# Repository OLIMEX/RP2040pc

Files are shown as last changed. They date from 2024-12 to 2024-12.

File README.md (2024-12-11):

# RP2040pc
All in one computer with 4 USB hosts, Stereo Audio, HDMI output. Supports USB Flash drives, USB keyboards, USB Gamepads.

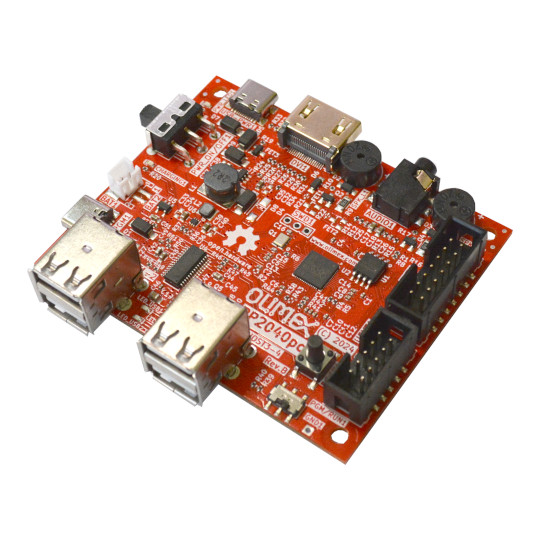
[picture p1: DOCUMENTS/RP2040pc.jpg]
RP2040pc


https://www.olimex.com/Products/RaspberryPi/RP2040pc/

## Licensee
* Hardware is released under CERN Open Hardware Licence Version 2 - Strongly Reciprocal
* Software is released under MIT Licensee
* Documentation is released under CC BY-SA 4.0

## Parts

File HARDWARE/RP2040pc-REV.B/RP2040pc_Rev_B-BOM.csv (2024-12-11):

Id | Designator | Footprint | Quantity | Designation | Supplier and ref
1 | MH1,MH3,MH4,MH2 | Mounting_Hole_Drill-3.3mm_Clerance-7mm | 4 | Mounting_Hole_NPTH
2 | R38,R44,R10,R20,R17,R49,R48,R18 | R_0402_5MIL_DWS | 8 | 2.2k/R0402
3 | R12,R13 | R_0402_5MIL_DWS | 2 | 150R/R0402
4 | R14,R31,R28,R25,R24,R27,R26,R29,R30,R15 | R_0402_5MIL_DWS | 10 | 270R/R0402
5 | FID5,FID6,FID4 | Fiducial1x3 | 3 | Fiducial
6 | FID2,FID3,FID1 | Fiducial1x3_Paste | 3 | Fiducial
7 | C17,C34,C37,C18,C39,C35 | C_0603_5MIL_DWS | 6 | 22uF/6.3V/20%/X5R/C0603
8 | C25,C1,C2,C3,C4,C5,C6,C7,C8,C9,C10,C14,C13,C44,C46,C26,C41,C49 | C_0402_5MIL_DWS | 18 | 100nF/10V/20%/X5R/C0402
9 | AUDIO1 | SCJ325P00XG0B02G | 1 | PJ-3.5-365-5P
10 | Q2,Q4 | SOT23 | 2 | BC817-40(SOT23)
11 | C11,C12 | C_0402_5MIL_DWS | 2 | 2.2uF/6.3V/20%/X5R/C0402
12 | C15,C16 | C_0402_5MIL_DWS | 2 | 18pF/50V/5%/C0G/C0402
13 | Q1,Q5 | TSX-3.2x2.5mm_GND(3) | 2 | Q12MHz/20pF/10ppm/4P/3.2x2.5mm
14 | R1,R45,R23,R46,R19 | R_0402_5MIL_DWS | 5 | 10k/R0402
15 | R2,R43 | R_0402_5MIL_DWS | 2 | NA(10k/R0402)
16 | R6,R8 | R_0402_5MIL_DWS | 2 | 100R/R0402
17 | R4,R5 | R_0402_5MIL_DWS | 2 | 27R/R0402
18 | U1 | SO-8_208mil | 1 | W25Q128JVSIQ
19 | U2 | QFN56_7x7_Pitch_0.4mm | 1 | RP2040(QFN-56_7x7mm_P0.4mm)
20 | BOOT1 | T1102D_6x6 | 1 | T1102D(6x6x9.5mm)
21 | SWD1 | HN1x3 | 1 | NA(HN1x3)
22 | R9,R16 | R_1206_5MIL_DWS | 2 | 47R/R1206
23 | DVI1 | HDMI-SWM-19_Paste | 1 | HDMI-SWM-19
24 | SPK_L1,SPK_R1 | Speaker_QMB-09B-03_1-Plus_2-Minus | 2 | Speaker_QMB-09B-03(1.5-5.0V_2.7kHz_F9.0mm*H5.5mm)
25 | D2,D3 | SOD-123_1C-2A_KA | 2 | 1N4148W/SOD123
26 | C40,C38,C32,C33 | C_0603_5MIL_DWS | 4 | NA(22uF/6.3V/20%/X5R/C0603)
27 | R35 | R_0402_5MIL_DWS | 1 | 1.05k/1%/R0402
28 | USB_HOST1-2,USB_HOST3-4 | USB_TWO_LEVEL | 2 | USBB1-FRWH-4A(USB-Ax2)
29 | LED_USB4,LED_USB3,LED_USB1,LED_USB2 | LED_0603_KA | 4 | LED/GREEN/0603
30 | U6 | SOT-563-6 | 1 | TPS62A02ADRLR(SOT-563-6)
31 | R40,R42,R41 | R_0402_5MIL_DWS | 3 | 470k/R0402
32 | C27,C28 | C_0805_5MIL_DWS | 2 | NA(47uF/6.3V/20%/X5R/C0805)
33 | C29,C19,C30 | C_0805_5MIL_DWS | 3 | 47uF/6.3V/20%/X5R/C0805
34 | R22,R21 | R_0402_5MIL_DWS | 2 | NA(2.2k/R0402)
35 | PWR_ON/OFF1 | SS-12D11G5 | 1 | SS-12D11G5
36 | EXT1 | GBH-254-SMT-14 | 1 | B-V-14-LF
37 | R33,R32,R7,R3 | R_0402_5MIL_DWS | 4 | 5.1k/1%/R0402
38 | U5 | SOT-23-5 | 1 | BL4054B-42TPRN(SOT23-5)
39 | CHARGING1 | LED_0603_KA | 1 | LED/YELLOW/0603
40 | D7,D8,D5,D1,D9 | SMA-KA | 5 | 1N5822/SS34/SMA
41 | UEXT1 | GBH-254-SMT-10 | 1 | P-B-V-10-LF
42 | GND1 | TEST_PAD40x70_SQUARE | 1 | TESTPAD
43 | C31 | C_0603_5MIL_DWS | 1 | 1uF/10V/10%/X5R/C0603
44 | R50 | R_0402_5MIL_DWS | 1 | 47k/R0402
45 | FET2,FET1 | SOT23 | 2 | NA(BSS138(SOT23-3))
46 | U4 | SSOP28_10x4mm_Pitch_0.64mm | 1 | FE1.1s_USB2.0-HUB
47 | PGM/RUN1 | SWITCH_SLIDE_IS-1390-G_TR | 1 | SWITCH SLIDE IS-1390-G TR
48 | U7 | SOT23-6 | 1 | MT3608(SOT23-6)
49 | C43,C45,C42 | C_0603_5MIL_DWS | 3 | 10uF/6.3V/20%/X5R/C0603
50 | U3 | SOT23-6 | 1 | CH217K(SOT23-6L)
51 | R51 | R_0402_5MIL_DWS | 1 | 100k/R0402
52 | USB-PGM1,USB-PWR1 | USB2.0_TYPE-C(A40-00119-A52-12)_Paste | 2 | USB-C-16P-F(A40-00119-A52-12)
53 | FET3 | SOT23 | 1 | WPM2015-3/TR
54 | R47 | R_0402_5MIL_DWS | 1 | 2.7k/1%/R0402
55 | C47,C48 | C_0402_5MIL_DWS | 2 | NA(27pF/50V/5%/C0G/C0402)
56 | BAT1 | LIPO_BAT_VERTICAL_DW02S | 1 | DW02S
57 | R37 | R_0402_5MIL_DWS | 1 | 49.9k/1%/R0402
58 | R36,R39 | R_0402_5MIL_DWS | 2 | 220k/R0402
59 | D6 | SOD-123_1C-2A_KA | 1 | 1N5819S4/SOD123
60 | C36 | C_0402_5MIL_DWS | 1 | NA(120pF/50V/5%/C0G/C0402)
61 | R11 | R_0402_5MIL_DWS | 1 | 33k/R0402
62 | D4 | SMA-KA | 1 | NA(1N5822/SS34/SMA)
63 | R34 | R_0402_5MIL_DWS | 1 | 8.25k/1%/R0402
64 | L1 | YS75_7X8MM | 1 | 2.2uH/3A/YS75/7x8
65 | PWR_LED1 | LED_0603_KA | 1 | LED/RED/0603
66 | BAT2 | PH2.0-2PWB | 1 | NA(PH2.0-2PWB)
67 | L2 | CD32 | 1 | 1.0uH/2.5A/DCR=30mR/20%/3.00x3.00x1.50mm/CD32(SWPA3015S1R0MT)
68 | HCEC1,HSDA1,HSCL1,HHPD1,+5V_USB1,GND2,VBUS1,+5V1,+1V1,VBAT1,VBUS_PWR1,+3.3V1 | TESTPAD_40-ROUND | 12 | TESTPAD

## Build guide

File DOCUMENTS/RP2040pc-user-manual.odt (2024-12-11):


RP2040pc

User Manual

Rev.1.0 December 2024 olimex.com

# What is RP2040pc

RP2040pc is complete all in one computer based on RP2040 Dual core Cortex-M0 processor from the Raspberry Pi foundation.

The features of RP2040pc are:

- RP2040 with 16MB of SPI Flash, easy to load new firmware via drag and drop virtual drive
- DVI/HDMI output
- USB with 4 USB2.0 hub which can be used for programming and to connect to keyboard, mouse, USB Flash, USB Gamepads etc
- Stereo Audio buzzer which you can enable/disable
- Audio 3.5mm connector for external audio amplifier
- USB-C connector for power supply
- USB-C connector for programming
- UEXT connector with I2C, UART and SPI for connecting to external boards
- Power switch
- Programming/Execution switch
- RP2040 programming bootloader button
- four mounting holes 3.3mm diameter
- Lipo battery charger which allow the board to run from LiPo battery.
- Dimension 80x65mm
  RP2040pc is Open Source Hardware, all CAD files and firmware and available, so people can study and modify.

+ Important notice: If RP2040pc is not mounted in box be careful to not place it on metal surface, nor drop metal objects on top of the PCB! This will lead to damage.

## Order codes for RP2040pc and accessories:

RP2040pc (https://www.olimex.com/Products/RaspberryPi/RP2040pc/) RP2040 all in one computer with 4 USB hosts and HDMI display

USB-KEYBOARD-PS2 (https://www.olimex.com/Products/USB-Modules/USB-KEYBOARD-PS2/) Keyboard which is compatible with RP2040pc

USB-GAMEPAD (https://www.olimex.com/Products/Retro-Computers/USB-GAMEPAD/) USB Gamepad supported by Reload emulator

USB-CABLE-AM-USB3-C (https://www.olimex.com/Products/Components/Cables/USB-CABLE-AM-USB3-C/) High speed, High current cable for power supply and programming

CABLE-HDMI-50CM (https://www.olimex.com/Products/Components/Cables/CABLE-HDMI-50CM/) HDMI cable

UEXT modules (https://www.olimex.com/Products/Modules/) many UEXT modules which can connect to Neo6502 UEXT connector

BOX- (https://www.olimex.com/Products/RaspberryPi/BOX-RP2040PC/)RP2040pc (https://www.olimex.com/Products/RaspberryPi/BOX-RP2040PC/) plastic box for RP2040pc

(https://www.olimex.com/Products/Components/Cables/USB-CABLE-AM-USB3-C/)

# HARDWARE

## RP2040pc layout:

USB-C

power supply

DVI/HDMI output

Stereo Audio 3.5mm jack

Left audio

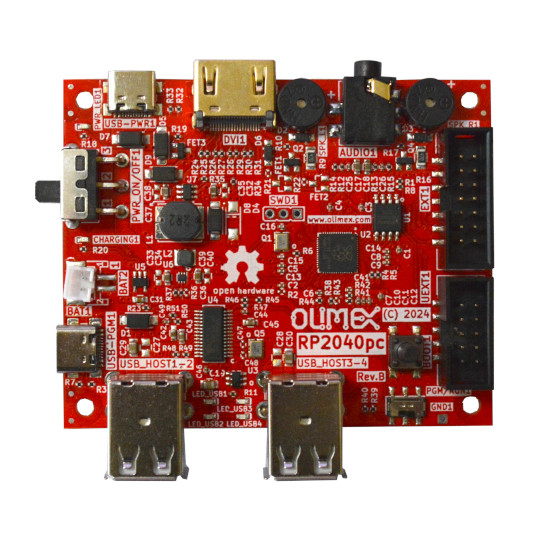
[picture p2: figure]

Right audio

ON/OFF switch

EXT1 connector

LiPo battery

UEXT connector

BOOT button

USB-C programming

Programing / RUN switch

USB2.0 host 1 and 2

USB2.0 host 3 and 4

## RP2040pc EXT1 connector:

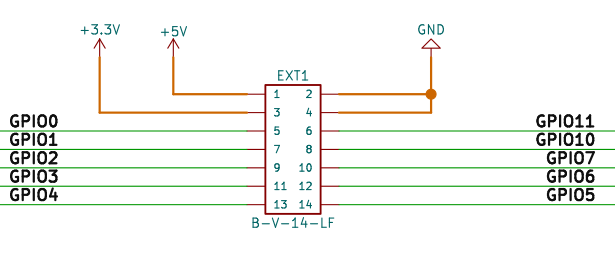
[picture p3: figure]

## UEXT connector:

UEXT connector stands for Universal EXTension connector and contain +3.3V, GND, I2C, SPI, UART signals.

UEXT connector can be in different shapes.

The original UEXT connector is 0.1” 2.54mm step boxed plastic connector. All signals are with 3.3V levels.

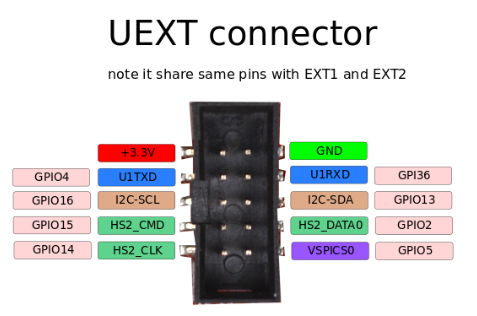
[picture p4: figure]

Olimex has developed number of MODULES (https://www.olimex.com/Products/Modules/) with this connector. There are temperature, humidity, pressure, magnetic field, light sensors. Modules with LCDs, LED matrix, Relays, Bluetooth, Zigbee, WiFi, GSM, GPS, RFID, RTC, EKG, sensors and etc.

RP2040pc UEXT connector is wired to RP2040 GPIOs as follows:

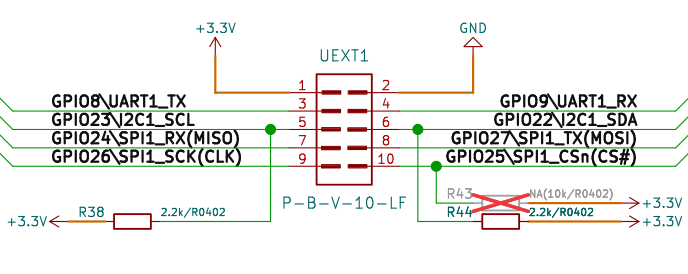
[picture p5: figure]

## RP2040pc schematics:

RP2040pc latest schematic is on GitHub (https://github.com/OLIMEX/Neo6502/blob/main/HARDWARE/Neo6502-rev-B/Neo6502_Rev_B.pdf)

# SOFTWARE:

RP2040pc can be programmed with RaspberryPi C-SDK or MicroPython SDK.

(https://github.com/vsladkov/reload-emulator)

For the retro computing fans the Reload (https://github.com/vsladkov/reload-emulator) emulator written by Veselin Sladkov (veselin.sladkov@gmail.com) supports RP2040pc and can emulate Apple ][, Apple][e, Oric Atmos, Pravetz 82, Pravetz 8D and all games from Total Replay 5.2 are supported.

If you want to build reload emulator you will need some ROMs and Disk images which are hosted on olimex’s ftp (https://ftp.olimex.com/Neo6502/).

The .uf2 image of the Reload is on ftp (https://ftp.olimex.com/Neo6502/RP2040pc/apple2e%206.uf2). You will need Flash drive formatted with FAT and with copy of Total relay 5.2 from the ftp (https://ftp.olimex.com/Neo6502/RP2040pc/Total%20Replay%20v5.2.hdv).

## Programming RP2040

The RP2040 firmware is UF2 file. You can get pre-build firmware of reload emulator on olimex’s ftp.

To program the .uf2 files you need USB-A to USB-C cable like USB-CABLE-AM-USB3-C (https://www.olimex.com/Products/Components/Cables/USB-CABLE-AM-USB3-C/).

1. Disconnect the power supply from USB-PWR1 connector and connect it to USB-PGM1 connector.

2. Move PGM/RUN1 switch to PGM position.

3. Press the BOOT1 button and switch on the power supply with PWR_ON/OFF1 switch then release BOOT1 button.

4. You will see on your computer new disk drive RPI-RP2.

5. Copy the .uf2 file to this drive, once it’s copied the drive will disappear.

6. Switch OFF the PWR_ON/OFF1 switch

7. Move PGM/RUN1 switch to RUN position.

8. Disconnect the USB-C cable from USB-PGM1 and connect to USB-PWR1 connector.

9. Switch ON power supply.

# Revision History

Revision 1.0 December 2024

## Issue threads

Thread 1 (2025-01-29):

Typo: "total relay 5.2 ..." etc. p.11 and notes about power supplies, Total Reload installation and loading times

Twenkid, 2025-01-29:
_The .uf2 image of the Reload is on ftp. You will need Flash drive formatted with FAT and with copy of
Total relay 5.2 from the ftp._

--> "need **a** Flash drive" ... Total re**p**lay 5.2

Observations: in Run mode, the power from my PC USB3 port didn't supply enough power and the Flash drive with which I tried (Kingston G3 8GB) couldn't start properly (it's with a light when active, which was just pulsating once in a few seconds).

**This info also could be helpful:**

You can also use SD or micro-SD cards with a card reader.

Q: Can you reuse a Pen drive with other files or the drive should contain only the file: "Total Replay v5.2.hdv"?
A: Yes, you can have other files, just put this one in the root directory.

Q: How quickly it should load?
A: It depends on your pen drive. With a decent one it may take a few seconds to show the initial screen with the games and then switch the games in a moment. However note that if you use a slow and overloaded drive it may take many minutes to load.

Twenkid, 2025-01-29:
Tested: Using the SD-card to USB adapter also required a dedicated power source, at least my PC's port didn't boot the system.

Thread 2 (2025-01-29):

Feature request: a Soft Restart Button

Twenkid, 2025-01-29:
In order to extend the life of the ON-OFF switch if playing "Total Reload" etc., currently a cold On-Off is required for changing the game.

TsvetanUsunov, 2025-01-29:
I believe Reload does this with keyboard F12

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

Twenkid, 2025-01-29:
Right, it worked, thanks! ("To use F12 as RESET button (both Apple ][ and Oric)" ... for Neo6502 , for RP2040pc it works out of the box).
One issue in Total Replay 5.2, the image from your FTP: Bubble Bobble crashed when starting, exiting tothe monitor.  4B09- A=4D X-00  Y=00 P=34 S=F6...  I tried it because on the Neo6502 it seemed to hang as well (without monitor), when we tried to play.

I tested with a file downloaded from Archive: https://archive.org/details/TotalReplay  - the same error - posting to https://github.com/a2-4am/4cade

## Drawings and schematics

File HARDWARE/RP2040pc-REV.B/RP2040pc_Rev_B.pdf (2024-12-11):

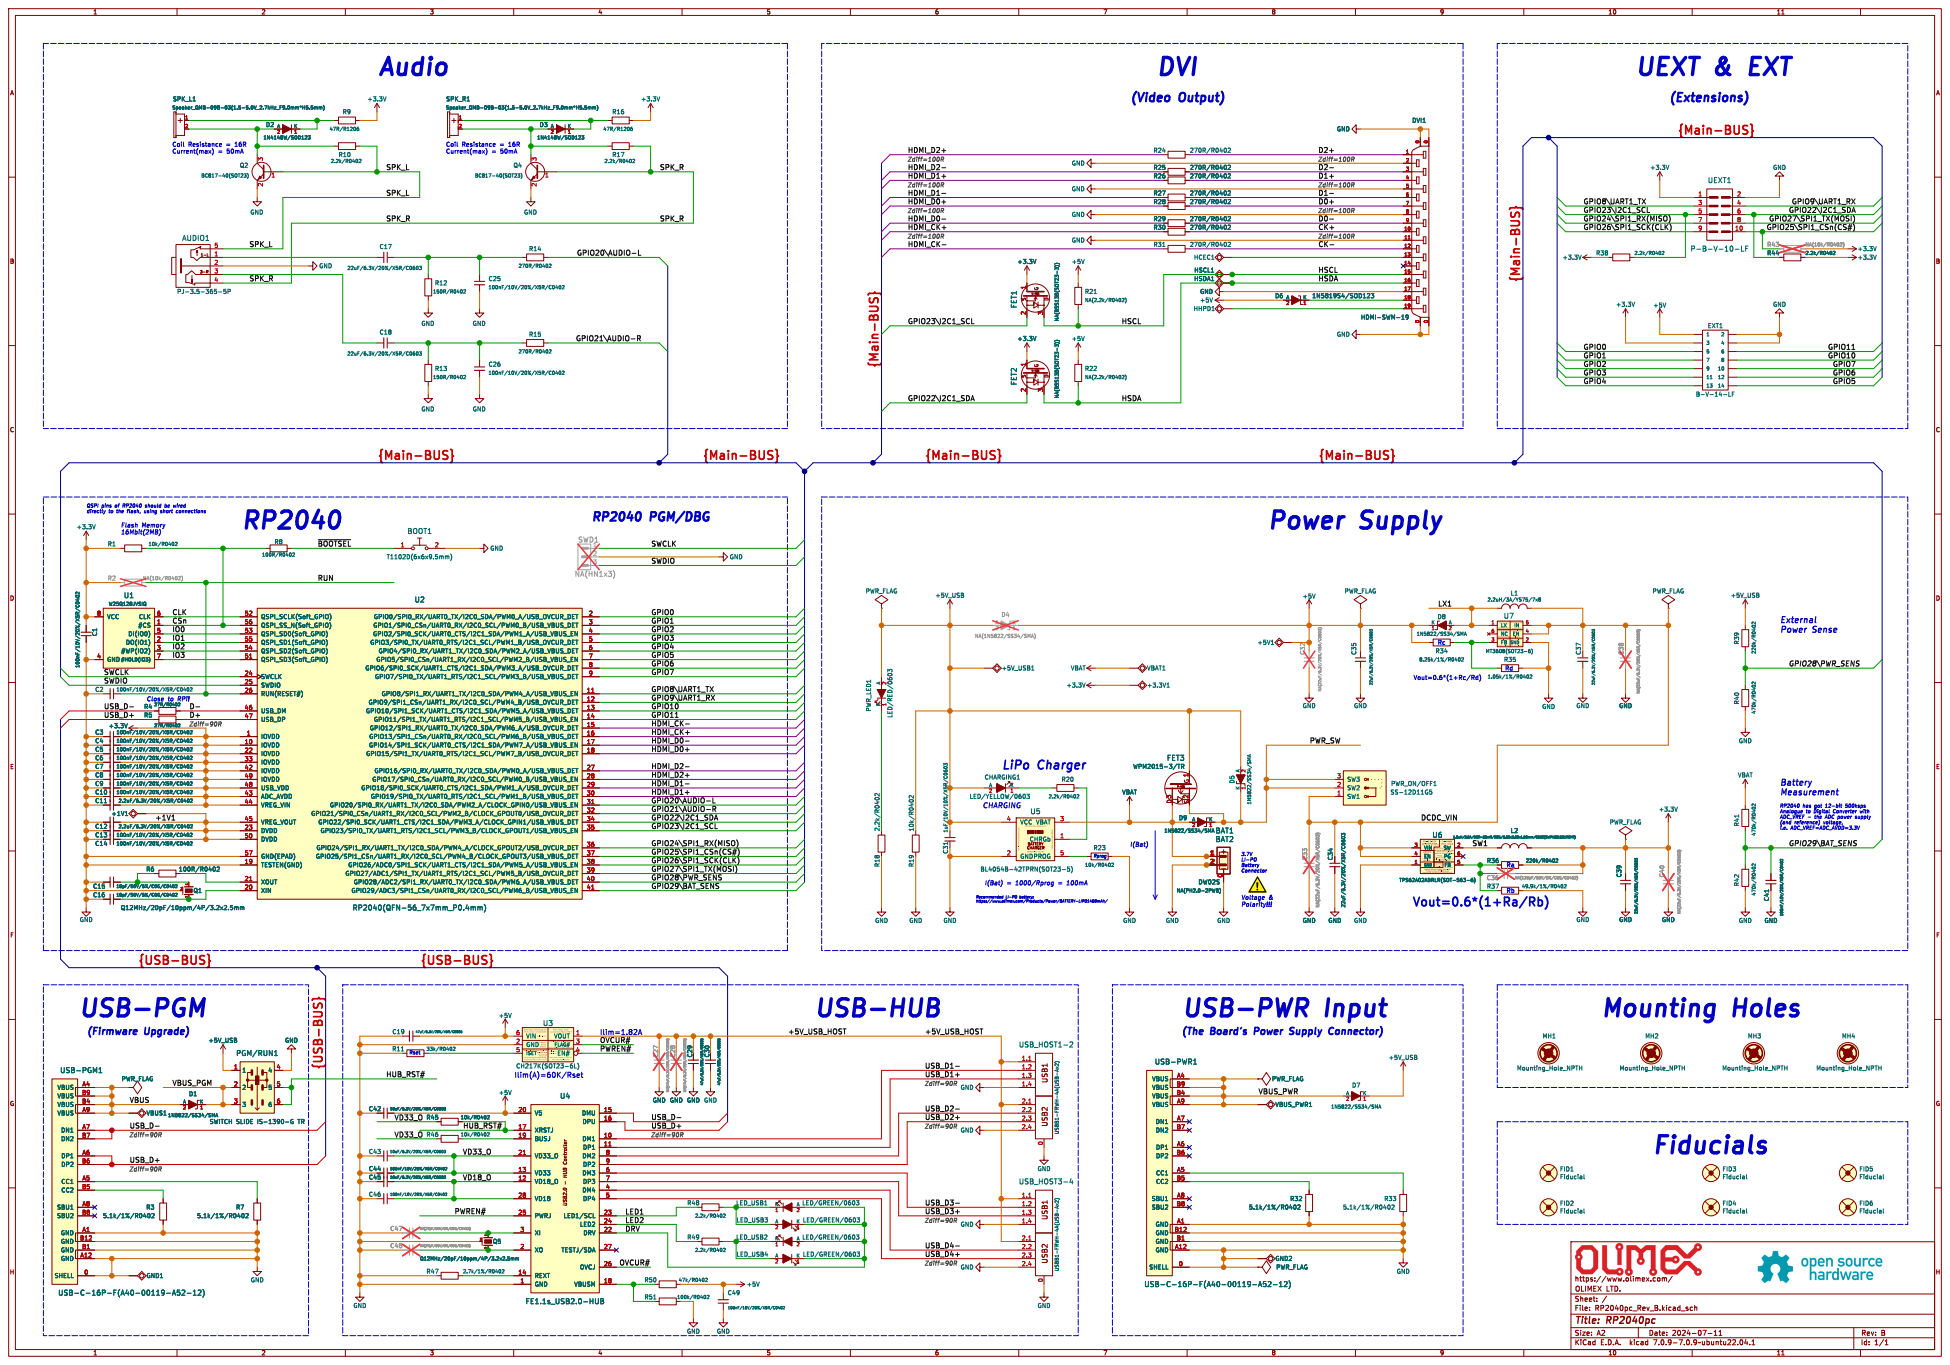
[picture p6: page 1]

GND GND

QSPI pins of RP2040 should be wired

MT3608(SOT23-6) L1
QuiescentCurrent(PFM)=200uA(Max) QuiescentCurrent(PWM)=2.2mA(Max) RecommendedInductorvalues:up to 22uH.

LX1 {USB-BUS} {USB-BUS}

The inductorshouldhavelow corelossat 1.2MHz andlow DCR for betterefficiency. RecommendedInput/OutputCapacitors: 22uF/X5R(X7R). Schottkydiodeis a goodchoicefor MT3608

Current(Shutdown)=1uA(Max) FB InputBiasCurrent=-50nA(min) FB Voltage=0.6V(Typical) OperatingInputVoltage
Vout=0.6*(1+Rc/Rd) LX

because of its low forwardvoltagedropandfast reversesrecovery. V(ENH)=1.5V(Min)

V(ENL)=0.4V(Max) Vin=(2-24)VDC

Cout=(10~22)uF/6.3V/X5Rþÿ(Vout"e1.8V). 22uFRecommended! Cout=22uF/6.3V/X5Rþÿ(1.2V"dVout<1.8V) Cout=44uF/6.3V/X5Rþÿ(0.6V"dVout<1.2V) DCR<50mR

In casea loweroutputrippleisdesired,higheroutputcapacitancecanhelpreducetheripple. Lx=1.0uH
2 VIN
(SOT563-6) A 0.47uHinductorcanalsobe usedwith thesamerecommendedoutput capacitorsfortheTPS62A02x. a largervaluereducesinputvoltageripple. Cin=4.7uF/6.3V/X5R
Ra Vout=0.6*(1+Ra/Rb)

Donotfloat. Enablecontrol. FB Input Current,I(FB)=100nA(max) FeedbackReferenceVoltage,V(REF)=0.6V
Rb mustnotbehigherthanþÿ100k© toprovideacceptablenoisesensitivity. ShutdownCurrentI(SHDN)=0.01-2uA

connectedto USBportVBUS Currentlimiting thresholdsetting, externalresistorRsetto GND to setIset ground

(The Board's Power Supply Connector)

alarmopen-drainoutput,activelow Common

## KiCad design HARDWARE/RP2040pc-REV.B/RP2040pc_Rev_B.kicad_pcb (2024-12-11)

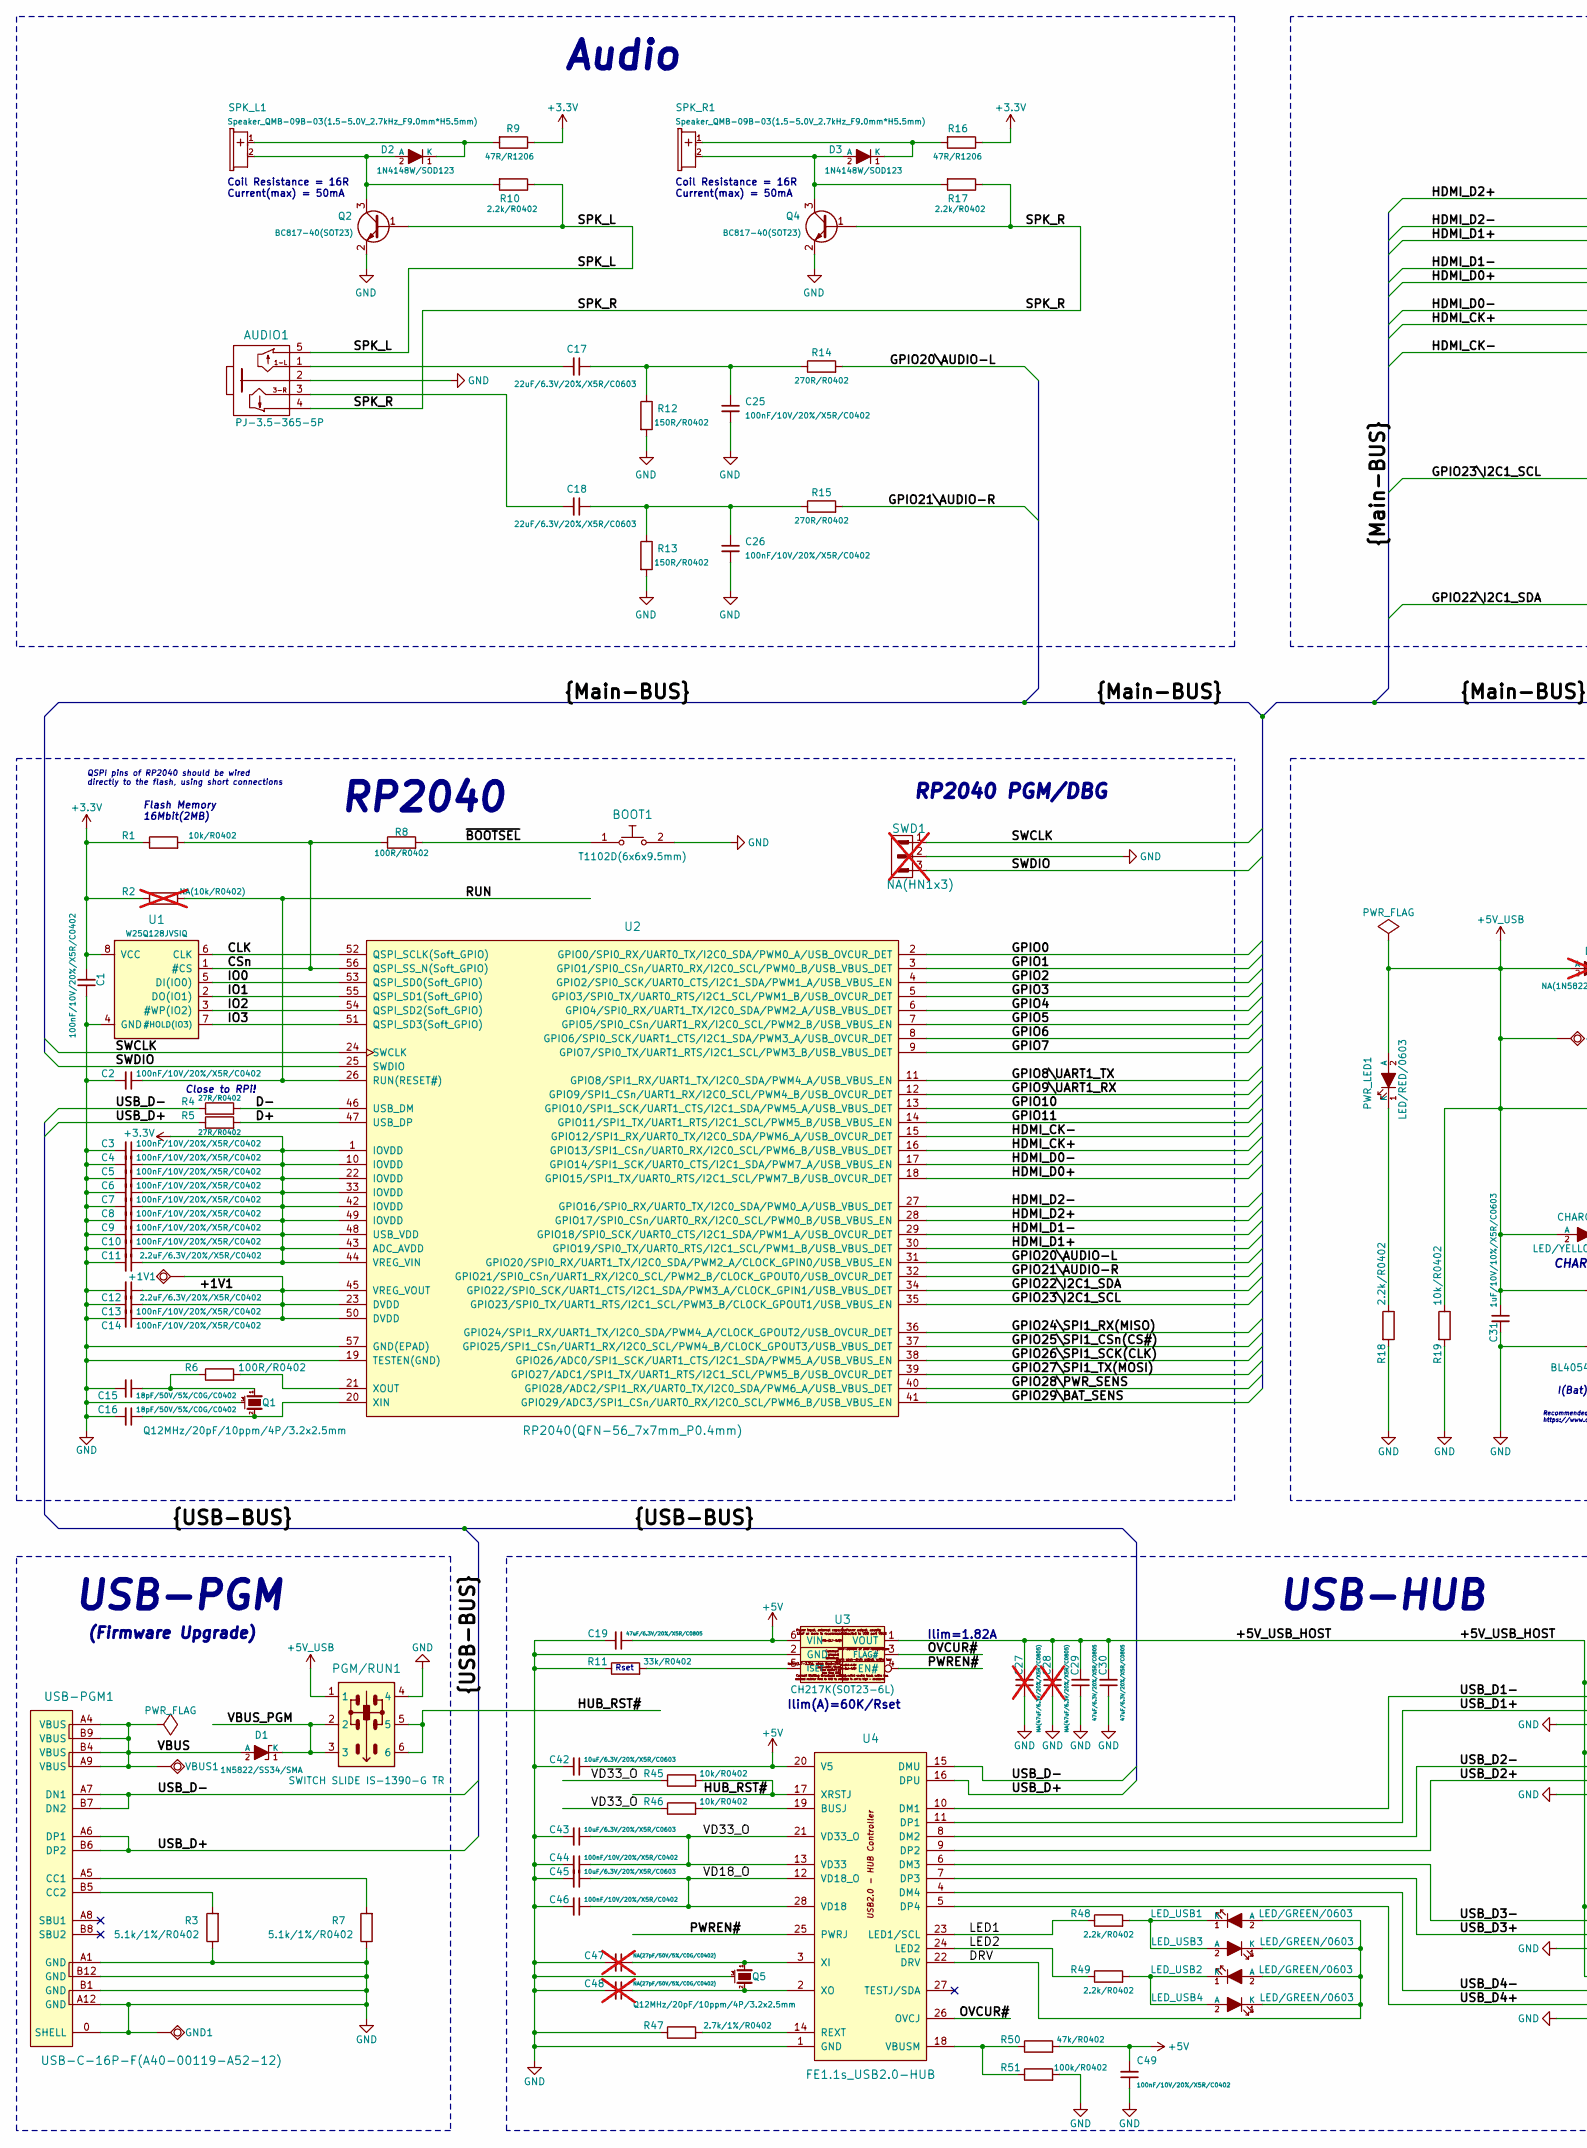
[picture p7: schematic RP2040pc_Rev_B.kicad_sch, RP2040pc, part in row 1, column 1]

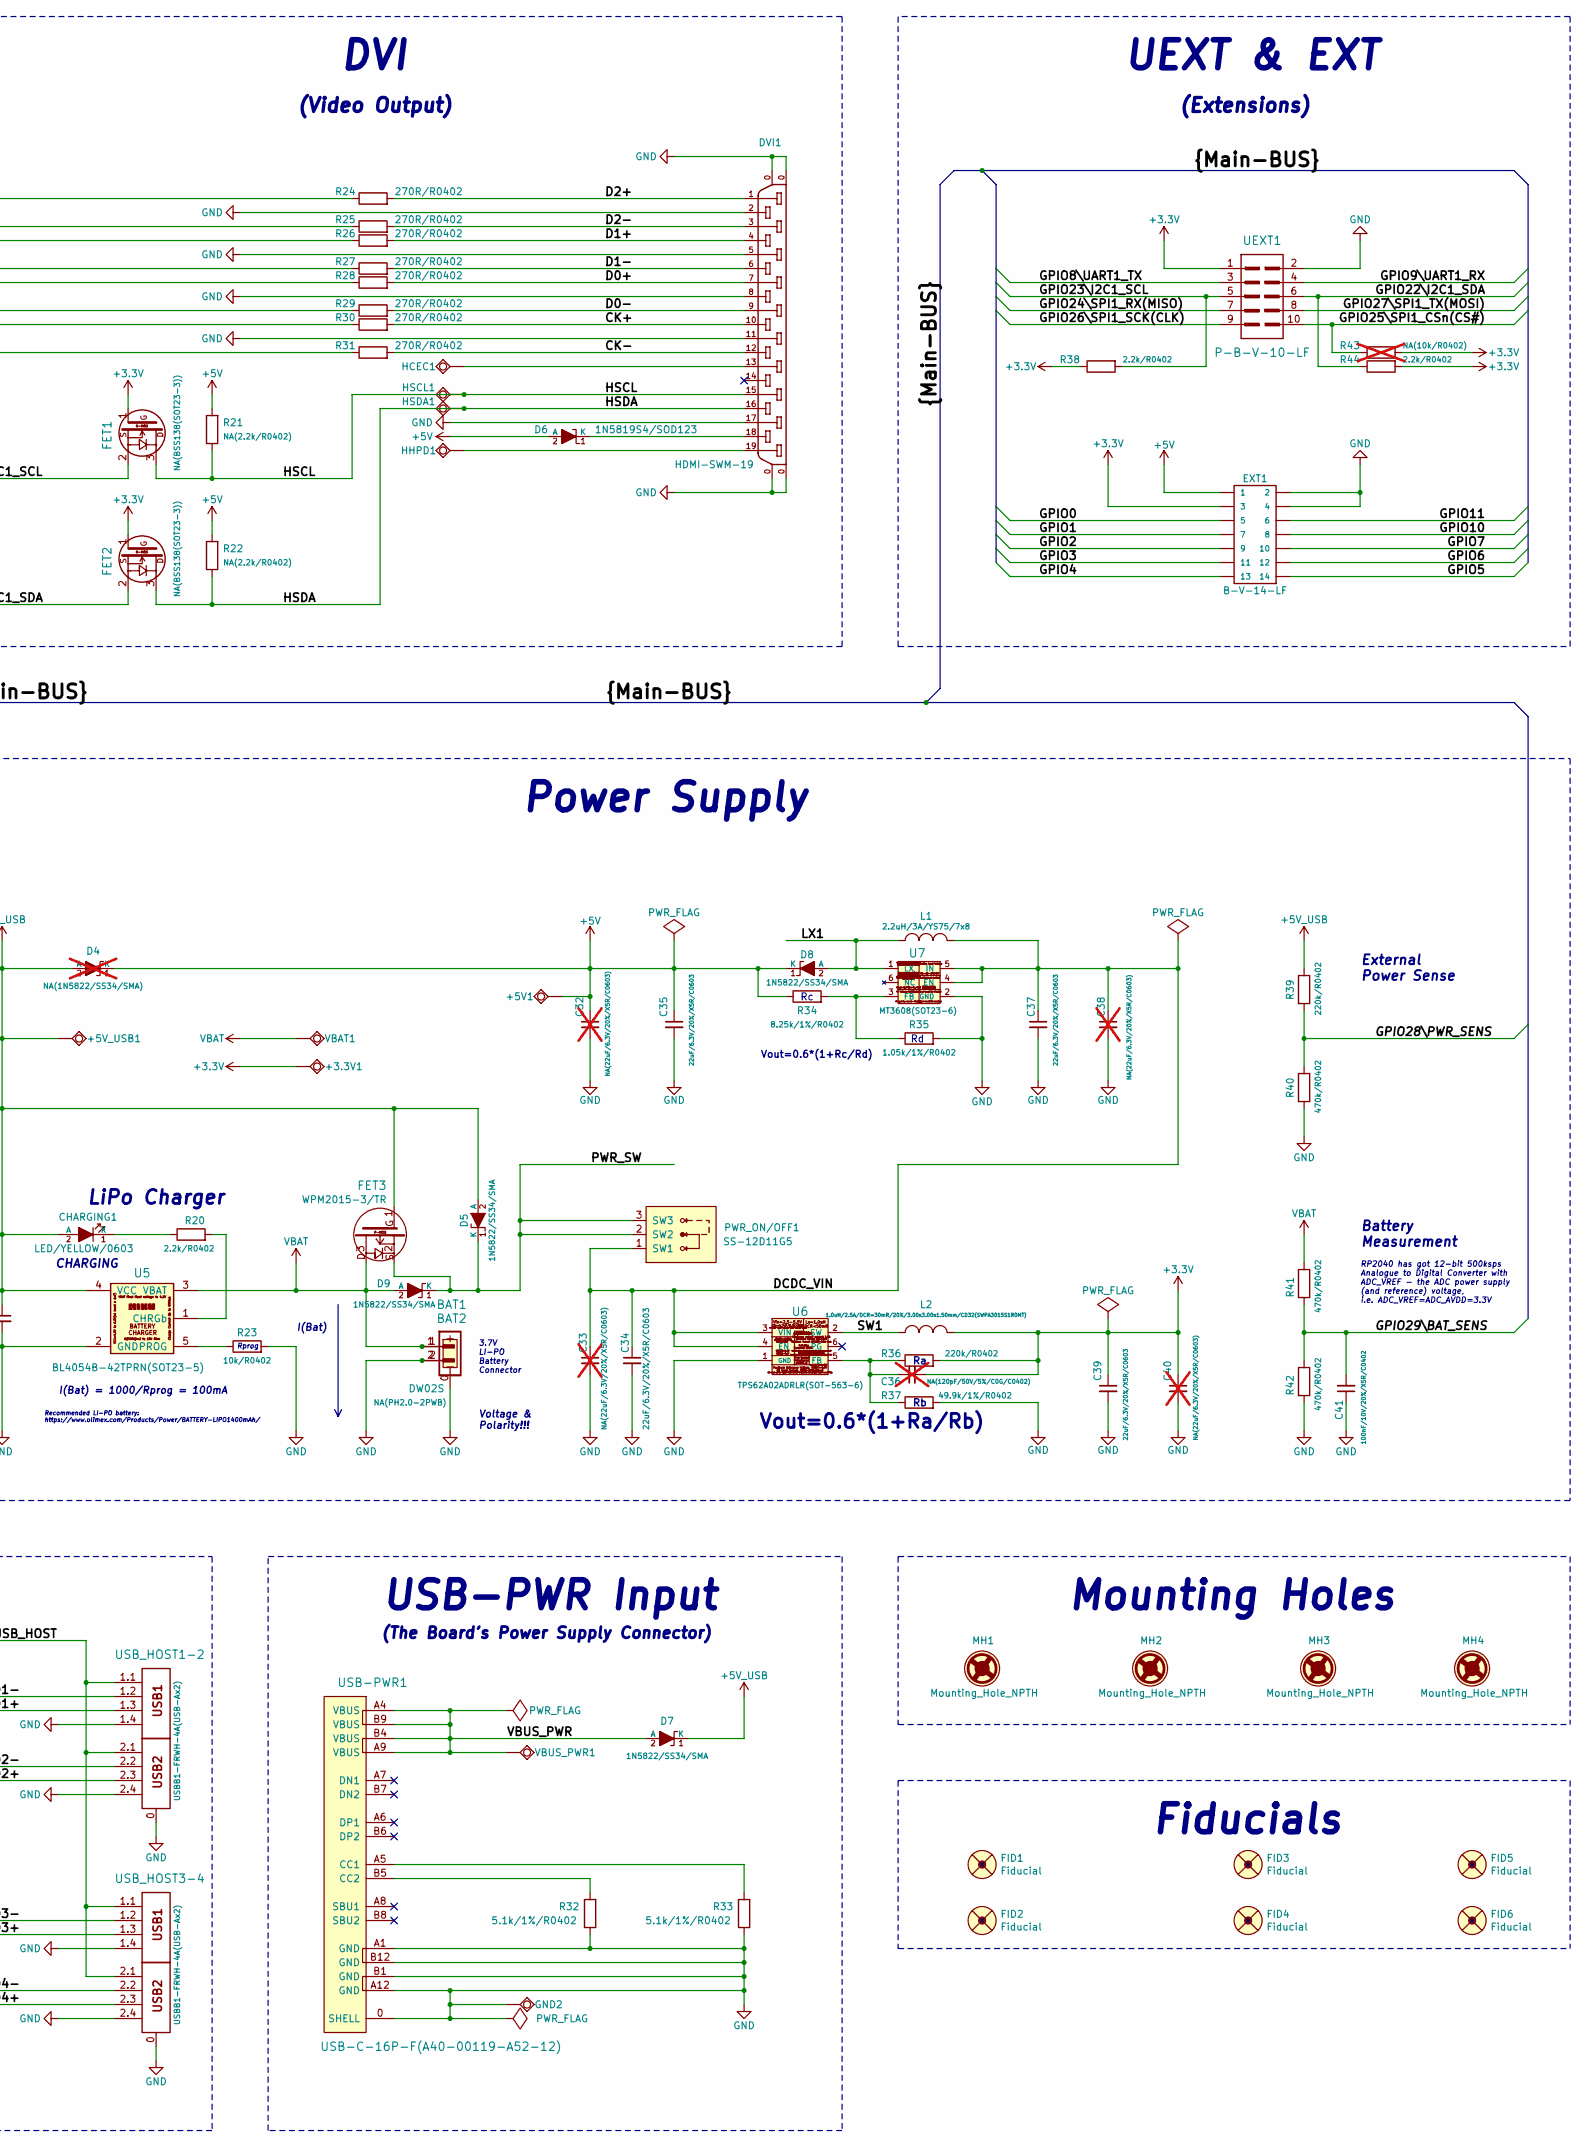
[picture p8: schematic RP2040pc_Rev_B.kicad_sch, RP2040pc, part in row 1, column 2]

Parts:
+1V1, +3.3V1, +5V1, +5V_USB1: TESTPAD; TESTPAD_40-ROUND
AUDIO1: PJ-3.5-365-5P; SCJ325P00XG0B02G
BAT1: DW02S; LIPO_BAT_VERTICAL_DW02S
BAT2: NA(PH2.0-2PWB); PH2.0-2PWB
BOOT1: T1102D(6x6x9.5mm); T1102D_6x6
C1, C2, C3, C4, C5, C6, C7, C8, C9, C10, C13, C14, C25, C26, C41, C44, C46, C49: 100nF/10V/20%/X5R/C0402; C_0402_5MIL_DWS
C11, C12: 2.2uF/6.3V/20%/X5R/C0402; C_0402_5MIL_DWS
C15, C16: 18pF/50V/5%/C0G/C0402; C_0402_5MIL_DWS
C17, C18, C34, C35, C37, C39: 22uF/6.3V/20%/X5R/C0603; C_0603_5MIL_DWS
C19, C29, C30: 47uF/6.3V/20%/X5R/C0805; C_0805_5MIL_DWS
C27, C28: NA(47uF/6.3V/20%/X5R/C0805); C_0805_5MIL_DWS; not fitted
C31: 1uF/10V/10%/X5R/C0603; C_0603_5MIL_DWS
C32, C33, C38, C40: NA(22uF/6.3V/20%/X5R/C0603); C_0603_5MIL_DWS; not fitted
C36: NA(120pF/50V/5%/C0G/C0402); C_0402_5MIL_DWS; not fitted
C42, C43, C45: 10uF/6.3V/20%/X5R/C0603; C_0603_5MIL_DWS
C47, C48: NA(27pF/50V/5%/C0G/C0402); C_0402_5MIL_DWS; not fitted
CHARGING1: LED/YELLOW/0603; LED_0603_KA
D1, D5, D7, D8, D9: 1N5822/SS34/SMA; SMA-KA
D2, D3: 1N4148W/SOD123; SOD-123_1C-2A_KA
D4: NA(1N5822/SS34/SMA); SMA-KA; not fitted
D6: 1N5819S4/SOD123; SOD-123_1C-2A_KA
DVI1: HDMI-SWM-19; HDMI-SWM-19_Paste
EXT1: B-V-14-LF; GBH-254-SMT-14
FET1, FET2: NA(BSS138(SOT23-3)); SOT23
FET3: WPM2015-3/TR; SOT23
FID1, FID2, FID3: Fiducial; Fiducial1x3_Paste
FID4, FID5, FID6: Fiducial; Fiducial1x3
GND1: TESTPAD; TEST_PAD40x70_SQUARE
GND2: TESTPAD; TESTPAD_40-ROUND
HCEC1: TESTPAD; TESTPAD_40-ROUND
HHPD1: TESTPAD; TESTPAD_40-ROUND
HSCL1: TESTPAD; TESTPAD_40-ROUND
HSDA1: TESTPAD; TESTPAD_40-ROUND
L1: 2.2uH/3A/YS75/7x8; YS75_7X8MM
L2: 1.0uH/2.5A/DCR=30mR/20%/3.00x3.00x1.50mm/CD32(SWP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; CD32
LED_USB1, LED_USB2, LED_USB3, LED_USB4: LED/GREEN/0603; LED_0603_KA
MH1, MH2, MH3, MH4: Mounting_Hole_NPTH; Mounting_Hole_Drill-3.3mm_Clerance-7mm
PGM/RUN1: SWITCH SLIDE IS-1390-G TR; SWITCH_SLIDE_IS-1390-G_TR
PWR_LED1: LED/RED/0603; LED_0603_KA
PWR_ON/OFF1: SS-12D11G5
Q1, Q5: Q12MHz/20pF/10ppm/4P/3.2x2.5mm; TSX-3.2x2.5mm_GND(3)
Q2, Q4: BC817-40(SOT23); SOT23
R1, R19, R23, R45, R46: 10k/R0402; R_0402_5MIL_DWS
R2, R43: NA(10k/R0402); R_0402_5MIL_DWS; not fitted
R3, R7, R32, R33: 5.1k/1%/R0402; R_0402_5MIL_DWS
R4, R5: 27R/R0402; R_0402_5MIL_DWS
R6, R8: 100R/R0402; R_0402_5MIL_DWS
R9, R16: 47R/R1206; R_1206_5MIL_DWS
R10, R17, R18, R20, R38, R44, R48, R49: 2.2k/R0402; R_0402_5MIL_DWS
R11: 33k/R0402; R_0402_5MIL_DWS
R12, R13: 150R/R0402; R_0402_5MIL_DWS
R14, R15, R24, R25, R26, R27, R28, R29, R30, R31: 270R/R0402; R_0402_5MIL_DWS
R21, R22: NA(2.2k/R0402); R_0402_5MIL_DWS
R34: 8.25k/1%/R0402; R_0402_5MIL_DWS
R35: 1.05k/1%/R0402; R_0402_5MIL_DWS
R36, R39: 220k/R0402; R_0402_5MIL_DWS
R37: 49.9k/1%/R0402; R_0402_5MIL_DWS
R40, R41, R42: 470k/R0402; R_0402_5MIL_DWS
R47: 2.7k/1%/R0402; R_0402_5MIL_DWS
R50: 47k/R0402; R_0402_5MIL_DWS
R51: 100k/R0402; R_0402_5MIL_DWS
SPK_L1: Speaker_QMB-09B-03(1.5-5.0V_2.7kHz_F9.0mm*H5.5mm); Speaker_QMB-09B-03_1-Plus_2-Minus
SPK_R1: Speaker_QMB-09B-03(1.5-5.0V_2.7kHz_F9.0mm*H5.5mm); Speaker_QMB-09B-03_1-Plus_2-Minus
SWD1: NA(HN1x3); HN1x3; not fitted
U1: W25Q128JVSIQ; SO-8_208mil
U2: RP2040(QFN-56_7x7mm_P0.4mm); QFN56_7x7_Pitch_0.4mm
U3: CH217K(SOT23-6L); SOT23-6
U4: FE1.1s_USB2.0-HUB; SSOP28_10x4mm_Pitch_0.64mm
U5: BL4054B-42TPRN(SOT23-5); SOT-23-5
U6: TPS62A02ADRLR(SOT-563-6); SOT-563-6
U7: MT3608(SOT23-6); SOT23-6
UEXT1: P-B-V-10-LF; GBH-254-SMT-10
USB-PGM1: USB-C-16P-F(A40-00119-A52-12); USB2.0_TYPE-C(A40-00119-A52-12)_Paste
USB-PWR1: USB-C-16P-F(A40-00119-A52-12); USB2.0_TYPE-C(A40-00119-A52-12)_Paste
USB_HOST1-2, USB_HOST3-4: USBB1-FRWH-4A(USB-Ax2); USB_TWO_LEVEL
VBAT1: TESTPAD; TESTPAD_40-ROUND
VBUS1: TESTPAD; TESTPAD_40-ROUND
VBUS_PWR1: TESTPAD; TESTPAD_40-ROUND

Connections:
+3.3V: +3.3V1.1 (Pad), C1.2, C3.1, C4.1, C5.1, C6.1, C7.1, C8.1, C9.1, C10.1, C11.1, C36.2, C39.1, C40.1, EXT1.3, FET1.1 (G), FET2.1 (G), L2.2, R1.1, R2.1, R9.1, R16.1, R36.2, R38.1, R43.2, R44.2, U1.8 (VCC), U2.1 (IOVDD), U2.10 (IOVDD), U2.22 (IOVDD), U2.33 (IOVDD), U2.42 (IOVDD), U2.43 (ADC_AVDD), U2.44 (VREG_VIN), U2.48 (USB_VDD), U2.49 (IOVDD), UEXT1.1
+5V: +5V1.1 (Pad), C19.1, C32.1, C35.1, C42.1, C49.2, D4.1 (K), D6.2 (A), D8.1 (K), EXT1.1, R21.2, R22.2, R34.1, R50.2, U3.6 (VIN), U4.20 (V5)
+5V_USB: +5V_USB1.1 (Pad), C31.1, CHARGING1.2 (A), D4.2 (A), D5.2 (A), D7.1 (K), FET3.1, PGM/RUN1.1, PWR_LED1.2 (A), R19.1, R39.1, U5.4 (VCC)
/+1V1: +1V1.1 (Pad), C12.1, C13.1, C14.1, U2.23 (DVDD), U2.45 (VREG_VOUT), U2.50 (DVDD)
/+5V_USB_HOST: C27.2, C28.2, C29.2, C30.2, U3.1 (VOUT), USB_HOST1-2.1.1, USB_HOST1-2.2.1, USB_HOST3-4.1.1, USB_HOST3-4.2.1
/CK+: DVI1.10, R30.2
/CK-: DVI1.12, R31.2
/CLK: U1.6 (CLK), U2.52 (QSPI_SCLK(Soft_GPIO))
/CSn: R1.2, R8.1, U1.1 (#CS), U2.56 (QSPI_SS_N(Soft_GPIO))
/D0+: DVI1.7, R28.2
/D0-: DVI1.9, R29.2
/D1+: DVI1.4, R26.2
/D1-: DVI1.6, R27.2
/D2+: DVI1.1, R24.2
/D2-: DVI1.3, R25.2
/D+: R5.2, U2.47 (USB_DP)
/D-: R4.2, U2.46 (USB_DM)
/DCDC_VIN: C33.1, C34.1, C37.1, C38.1, L1.2, PWR_ON/OFF1.1 (SW1), U6.3 (VIN), U6.4 (EN), U7.4 (EN), U7.5 (IN)
/DRV: LED_USB1.2 (A), LED_USB2.2 (A), LED_USB3.1 (K), LED_USB4.1 (K), U4.22 (DRV)
/GPIO0: EXT1.5, U2.2 (GPIO0/SPI0_RX/UART0_TX/I2C0_SDA/PWM0_A/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)
/GPIO1: EXT1.7, U2.3 (GPIO1/SPI0_CSn/UART0_RX/I2C0_SCL/PWM0_B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)
/GPIO2: EXT1.9, U2.4 (GPIO2/SPI0_SCK/UART0_CTS/I2C1_SDA/PWM1_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)
/GPIO3: EXT1.11, U2.5 (GPIO3/SPI0_TX/UART0_RTS/I2C1_SCL/PWM1_B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)
/GPIO4: EXT1.13, U2.6 (GPIO4/SPI0_RX/UART1_TX/I2C0_SDA/PWM2_A/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)
/GPIO5: EXT1.14, U2.7 (GPIO5/SPI0_CSn/UART1_RX/I2C0_SCL/PWM2_B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)
/GPIO6: EXT1.12, U2.8 (GPIO6/SPI0_SCK/UART1_CTS/I2C1_SDA/PWM3_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)
/GPIO7: EXT1.10, U2.9 (GPIO7/SPI0_TX/UART1_RTS/I2C1_SCL/PWM3_B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)
/GPIO8\UART1_TX: U2.11 (GPIO8/SPI1_RX/UART1_TX/I2C0_SDA/PWM4_A/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), UEXT1.3
/GPIO9\UART1_RX: U2.12 (GPIO9/SPI1_CSn/UART1_RX/I2C0_SCL/PWM4_B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), UEXT1.4
/GPIO10: EXT1.8, U2.13 (GPIO10/SPI1_SCK/UART1_CTS/I2C1_SDA/PWM5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)
/GPIO11: EXT1.6, U2.14 (GPIO11/SPI1_TX/UART1_RTS/I2C1_SCL/PWM5_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)
/GPIO20\AUDIO-L: R14.2, U2.31 (GPIO20/SPI0_RX/UART1_TX/I2C0_SDA/PWM2_A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)
/GPIO21\AUDIO-R: R15.2, U2.32 (GPIO21/SPI0_CSn/UART1_RX/I2C0_SCL/PWM2_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)
/GPIO22\I2C1_SDA: FET2.2 (S), R44.1, U2.34 (GPIO22/SPI0_SCK/UART1_CTS/I2C1_SDA/PWM3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), UEXT1.6
/GPIO23\I2C1_SCL: FET1.2 (S), R38.2, U2.35 (GPIO23/SPI0_TX/UART1_RTS/I2C1_SCL/PWM3_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), UEXT1.5
/GPIO24\SPI1_RX(MISO): U2.36 (GPIO24/SPI1_RX/UART1_TX/I2C0_SDA/PWM4_A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), UEXT1.7
/GPIO25\SPI1_CSn(CS#): R43.1, U2.37 (GPIO25/SPI1_CSn/UART1_RX/I2C0_SCL/PWM4_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), UEXT1.10
/GPIO26\SPI1_SCK(CLK): U2.38 (GPIO26/ADC0/SPI1_SCK/UART1_CTS/I2C1_SDA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), UEXT1.9
/GPIO27\SPI1_TX(MOSI): U2.39 (GPIO27/ADC1/SPI1_TX/UART1_RTS/I2C1_SCL/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), UEXT1.8
/GPIO28\PWR_SENS: R39.2, R40.1, U2.40 (GPIO28/ADC2/SPI1_RX/UART0_TX/I2C0_SDA/P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)
/GPIO29\BAT_SENS: C41.2, R41.2, R42.1, U2.41 (GPIO29/ADC3/SPI1_CSn/UART0_RX/I2C0_SCL/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)
/HDMI_CK+: R30.1, U2.16 (GPIO13/SPI1_CSn/UART0_RX/I2C0_SCL/PWM6_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)
/HDMI_CK-: R31.1, U2.15 (GPIO12/SPI1_RX/UART0_TX/I2C0_SDA/PWM6_A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)
/HDMI_D0+: R28.1, U2.18 (GPIO15/SPI1_TX/UART0_RTS/I2C1_SCL/PWM7_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)
/HDMI_D0-: R29.1, U2.17 (GPIO14/SPI1_SCK/UART0_CTS/I2C1_SDA/PWM7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)
/HDMI_D1+: R26.1, U2.30 (GPIO19/SPI0_TX/UART0_RTS/I2C1_SCL/PWM1_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)
/HDMI_D1-: R27.1, U2.29 (GPIO18/SPI0_SCK/UART0_CTS/I2C1_SDA/PWM1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)
/HDMI_D2+: R24.1, U2.28 (GPIO17/SPI0_CSn/UART0_RX/I2C0_SCL/PWM0_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)
/HDMI_D2-: R25.1, U2.27 (GPIO16/SPI0_RX/UART0_TX/I2C0_SDA/PWM0_A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)
/HSCL: DVI1.15, FET1.3 (D), HSCL1.1 (Pad), R21.1
/HSDA: DVI1.16, FET2.3 (D), HSDA1.1 (Pad), R22.1
/HUB_RST#: PGM/RUN1.5, PGM/RUN1.6, R45.2, U4.17 (XRSTJ)
/IO0: U1.5 (DI(IO0)), U2.53 (QSPI_SD0(Soft_GPIO))
/IO1: U1.2 (DO(IO1)), U2.55 (QSPI_SD1(Soft_GPIO))
/IO2: U1.3 (#WP(IO2)), U2.54 (QSPI_SD2(Soft_GPIO))
/IO3: U1.7 (#HOLD(IO3)), U2.51 (QSPI_SD3(Soft_GPIO))
/LED1: R48.1, U4.23 (LED1/SCL)
/LED2: R49.1, U4.24 (LED2)
/LX1: D8.2 (A), L1.1, U7.1 (LX)
/OVCUR#: U3.3 (FLAG#), U4.26 (OVCJ)
/PWREN#: U3.4 (EN#), U4.25 (PWRJ)
/PWR_SW: D5.1 (K), D9.1 (K), FET3.2, PWR_ON/OFF1.2 (SW2), PWR_ON/OFF1.3 (SW3)
/RUN: C2.1, R2.2, U2.26 (RUN(RESET#))
/SPK_L: AUDIO1.5, Q2.1 (B), R10.1
/SPK_R: AUDIO1.4, Q4.1 (B), R17.1
/SW1: L2.1, U6.2 (SW)
/SWCLK: SWD1.1, U2.24 (SWCLK)
/SWDIO: SWD1.3, U2.25 (SWDIO)
/USB_D1+: U4.11 (DP1), USB_HOST1-2.1.3
/USB_D1-: U4.10 (DM1), USB_HOST1-2.1.2
/USB_D2+: U4.9 (DP2), USB_HOST1-2.2.3
/USB_D2-: U4.8 (DM2), USB_HOST1-2.2.2
/USB_D3+: U4.7 (DP3), USB_HOST3-4.1.3
/USB_D3-: U4.6 (DM3), USB_HOST3-4.1.2
/USB_D4+: U4.5 (DP4), USB_HOST3-4.2.3
/USB_D4-: U4.4 (DM4), USB_HOST3-4.2.2
/USB_D+: R5.1, U4.16 (DPU), USB-PGM1.A6 (DP1), USB-PGM1.B6 (DP2)
/USB_D-: R4.1, U4.15 (DMU), USB-PGM1.A7 (DN1), USB-PGM1.B7 (DN2)
/VBUS: D1.2 (A), USB-PGM1.A4 (VBUS), USB-PGM1.A9 (VBUS), USB-PGM1.B4 (VBUS), USB-PGM1.B9 (VBUS), VBUS1.1 (Pad)
/VBUS_PGM: D1.1 (K), PGM/RUN1.2, PGM/RUN1.3
/VBUS_PWR: D7.2 (A), USB-PWR1.A4 (VBUS), USB-PWR1.A9 (VBUS), USB-PWR1.B4 (VBUS), USB-PWR1.B9 (VBUS), VBUS_PWR1.1 (Pad)
/VD18_O: C45.1, C46.1, U4.12 (VD18_O), U4.28 (VD18)
/VD33_O: C43.1, C44.1, R45.1, R46.1, U4.13 (VD33), U4.21 (VD33_O)
/~BOOTSEL: BOOT1.1, R8.2
GND: AUDIO1.2, BAT1.2, BAT2.0, BAT2.2, BOOT1.2, C1.1, C2.2, C3.2, C4.2, C5.2, C6.2, C7.2, C8.2, C9.2, C10.2, C11.2, C12.2, C13.2, C14.2, C15.2, C16.2, C19.2, C25.2, C26.2, C27.1, C28.1, C29.1, C30.1, C31.2, C32.2, C33.2, C34.2, C35.2, C37.2, C38.2, C39.2, C40.2, C41.1, C42.2, C43.2, C44.2, C45.2, C46.2, C47.2, C48.2, C49.1, DVI1.0 (22), DVI1.2, DVI1.5, DVI1.8, DVI1.11, DVI1.17, EXT1.2, EXT1.4, GND1.1 (Pad), GND2.1 (Pad), PGM/RUN1.4, Q1.3 (case), Q2.2 (E), Q4.2 (E), Q5.3 (case), R3.1, R7.1, R11.1, R12.2, R13.2, R18.2, R19.2, R23.2, R32.1, R33.1, R35.2, R37.2, R40.2, R42.2, R47.1, R51.2, SWD1.2, U1.4 (GND), U2.19 (TESTEN(GND)), U2.57 (GND(EPAD)), U3.2 (GND), U4.1 (GND), U5.2 (GND), U6.1 (GND), U7.2 (GND), UEXT1.2, USB-PGM1.0 (SHELL), USB-PGM1.A1 (GND), USB-PGM1.A12 (GND), USB-PGM1.B1 (GND), USB-PGM1.B12 (GND), USB-PWR1.0 (SHELL), USB-PWR1.A1 (GND), USB-PWR1.A12 (GND), USB-PWR1.B1 (GND), USB-PWR1.B12 (GND), USB_HOST1-2.0, USB_HOST1-2.1.4, USB_HOST1-2.2.4, USB_HOST3-4.0, USB_HOST3-4.1.4, USB_HOST3-4.2.4
unnamed: AUDIO1.1, C17.2
unnamed: AUDIO1.3, C18.2
unnamed: C15.1, Q1.1, R6.1
unnamed: C17.1, C25.1, R12.1, R14.1
unnamed: C18.1, C26.1, R13.1, R15.1
unnamed: CHARGING1.1 (K), R20.1
unnamed: D2.2 (A), Q2.3 (C), R10.2, SPK_L1.2 (MINUS)
unnamed: D2.1 (K), R9.2, SPK_L1.1 (PLUS)
unnamed: D3.2 (A), Q4.3 (C), R17.2, SPK_R1.2 (MINUS)
unnamed: D3.1 (K), R16.2, SPK_R1.1 (PLUS)
unnamed: D6.1 (K), DVI1.18
unnamed: DVI1.13, HCEC1.1 (Pad)
unnamed: DVI1.19, HHPD1.1 (Pad)
unnamed: LED_USB1.1 (K), LED_USB3.2 (A), R48.2
unnamed: LED_USB2.1 (K), LED_USB4.2 (A), R49.2
unnamed: PWR_LED1.1 (K), R18.1
unnamed: C16.1, Q1.2, U2.20 (XIN)
unnamed: R6.2, U2.21 (XOUT)
unnamed: R11.2, U3.5 (ISET)
unnamed: R46.2, U4.19 (BUSJ)
unnamed: R47.2, U4.14 (REXT)
unnamed: R50.1, R51.1, U4.18 (VBUSM)
unnamed: C47.1, Q5.1, U4.3 (XI)
unnamed: C48.1, Q5.2, U4.2 (XO)
unnamed: R20.2, U5.1 (CHRGb)
unnamed: R23.1, U5.5 (PROG)
unnamed: C36.1, R36.1, R37.1, U6.5 (FB)
unnamed: R34.2, R35.1, U7.3 (FB)
unnamed: R7.2, USB-PGM1.A5 (CC1)
unnamed: R3.2, USB-PGM1.B5 (CC2)
unnamed: R33.2, USB-PWR1.A5 (CC1)
unnamed: R32.2, USB-PWR1.B5 (CC2)
VBAT: BAT1.1, BAT2.1, D9.2 (A), FET3.3, R41.1, U5.3 (VBAT), VBAT1.1 (Pad)

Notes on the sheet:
Battery Measurement
(Firmware Upgrade)
Vout=0.6*(1+Ra/Rb)
Ilim(A)=60K/Rset
QSPI pins of RP2040 should be wired directly to the flash, using short connections
RP2040 has got 12-bit 500ksps Analogue to Digital Converter with ADC_VREF - the ADC power supply (and reference) voltage, i.e. ADC_VREF=ADC_AVDD=3.3V
Recommended LI-PO battery: https://www.olimex.com/Products/Power/BATTERY-LIPO1400mAh/
(Video Output)
(Extensions)
3.7V LI-PO Battery Connector
USB-PGM
USB-HUB
Close to RPi!
Vout=0.6*(1+Rc/Rd)
Coil Resistance = 16R Current(max) = 50mA
I(Bat)
LiPo Charger
UEXT & EXT
(The Board's Power Supply Connector)
I(Bat) = 1000/Rprog = 100mA
Mounting Holes
CHARGING
Fiducials
Audio
Power Supply
Ilim=1.82A
RP2040 PGM/DBG
DVI
RP2040
USB-PWR Input
Voltage & Polarity!!!
External Power Sense
Flash Memory 16Mbit(2MB)
Rset
Rprog

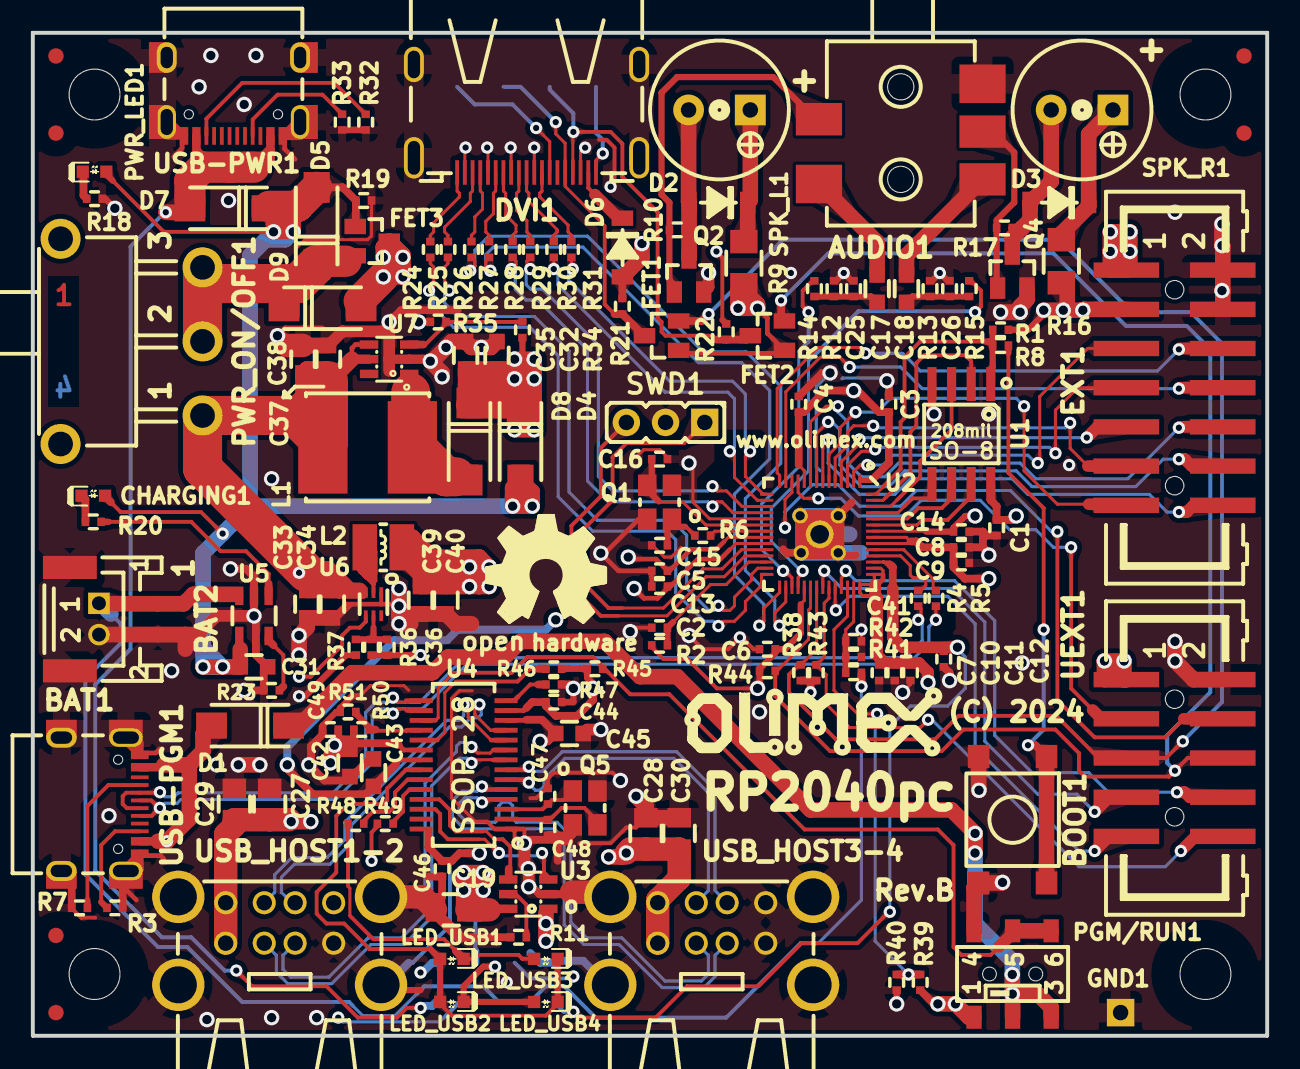
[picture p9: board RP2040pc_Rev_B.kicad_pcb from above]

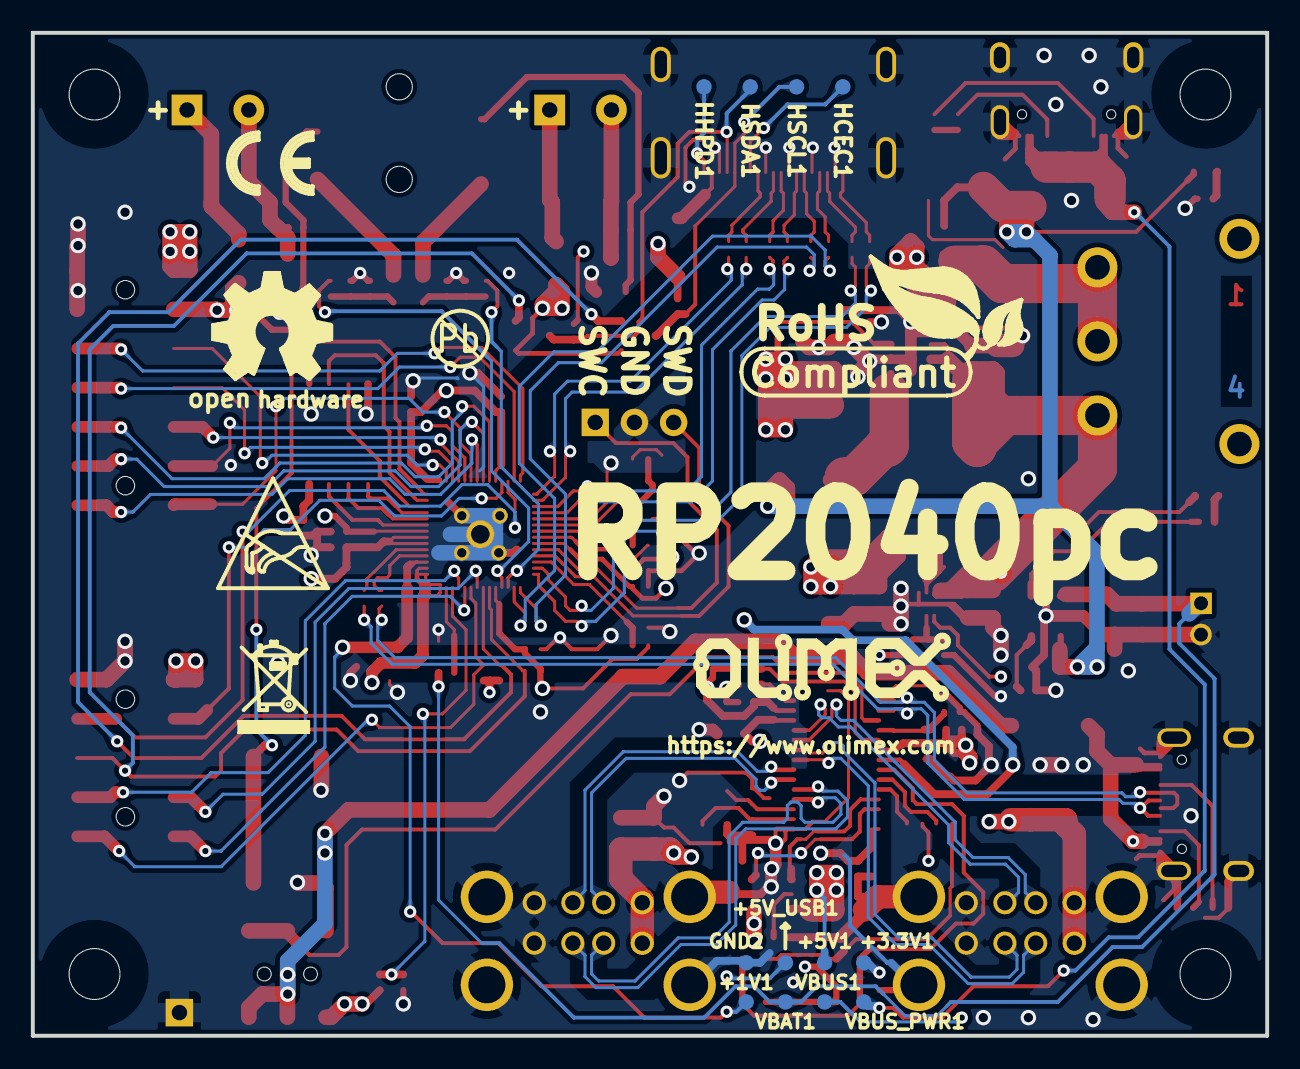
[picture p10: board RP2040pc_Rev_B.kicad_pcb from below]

Board: 4 copper layers, 80.0 x 65.0 mm, 174 parts (19 on the bottom side), 118 nets.

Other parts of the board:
Logo_OLIMEX_TB: Logo_OLIMEX_TB
Logo_OLIMEX_TB-Top: Logo_OLIMEX_TB
Sign_Antistatic: Sign_Antistatic
Sign_CE: CE_Sign
Sign_OSHW_8x8, Sign_OSHW_8x8-Top: Sign_OSHW_8x8
Sign_PB-Free: Sign_PB-Free
Sign_RecycleBin: Sign_RecycleBin; Sign_RecycleBin_1
Sign_RoHS: Sign_RoHS; Sign_RoHS_1

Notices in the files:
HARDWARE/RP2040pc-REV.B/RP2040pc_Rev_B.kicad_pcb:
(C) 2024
